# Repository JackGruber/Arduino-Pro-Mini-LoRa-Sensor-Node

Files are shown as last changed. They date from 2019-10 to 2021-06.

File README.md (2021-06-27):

# Arduino Pro Mini TTN LoRaWAN sensor node

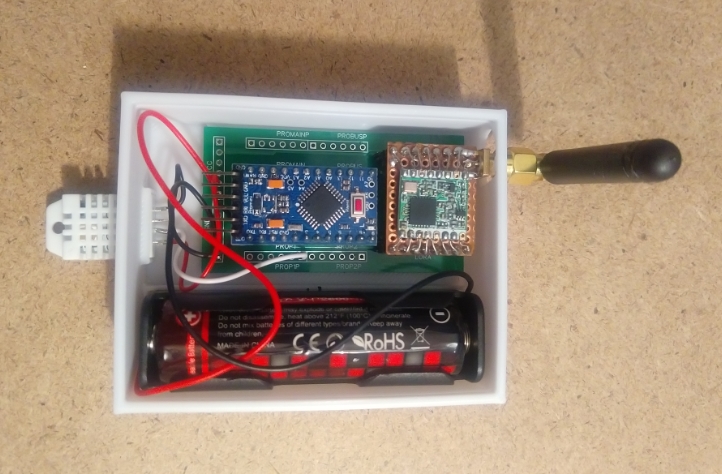
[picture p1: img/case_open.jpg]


`Arduino Pro Mini` TTN LoRaWAN Node with `DHT22` and `RFM95` module powered by an 18650 protected battery.  
The Arduino was converted to [LowPower](https://jackgruber.github.io/2019-12-27-Low-power-Arduino-Pro-Mini/) by desoldering the power LED and the voltage converter.

## Circuit

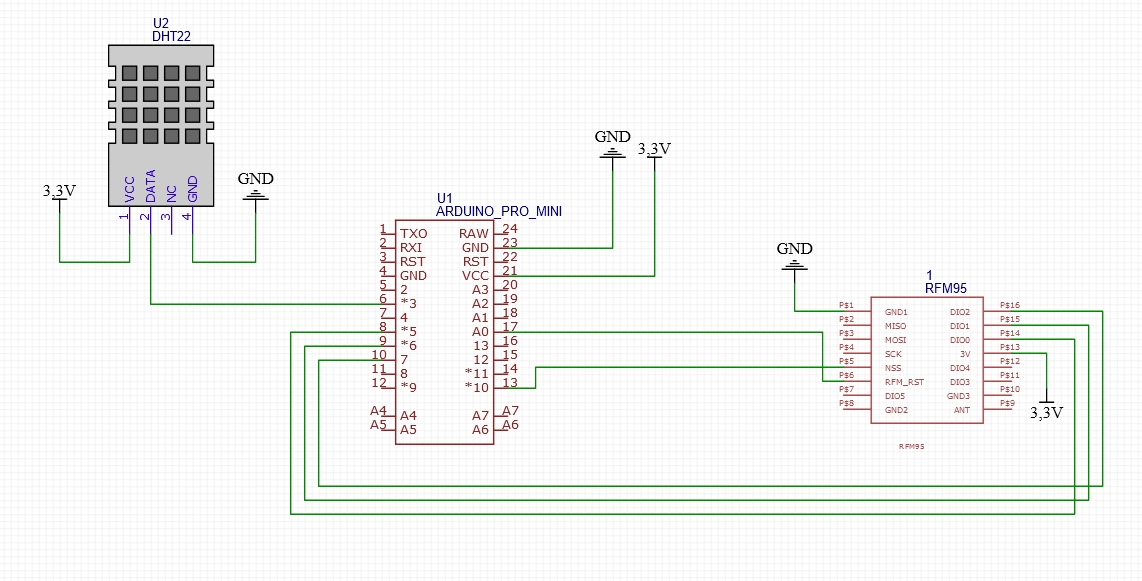
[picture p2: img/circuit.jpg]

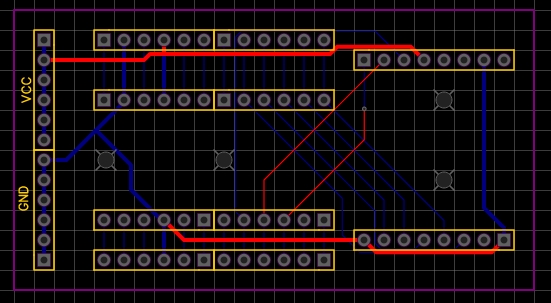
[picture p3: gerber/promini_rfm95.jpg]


## Case

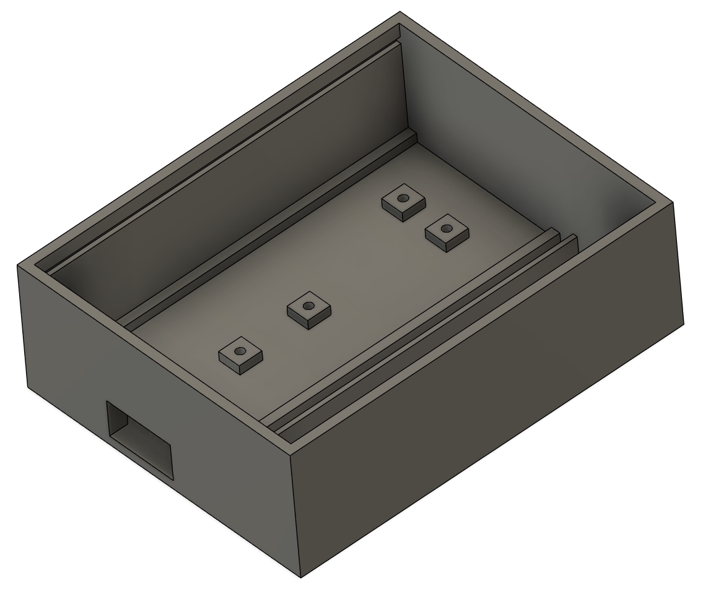
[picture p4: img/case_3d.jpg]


## Diagrams 
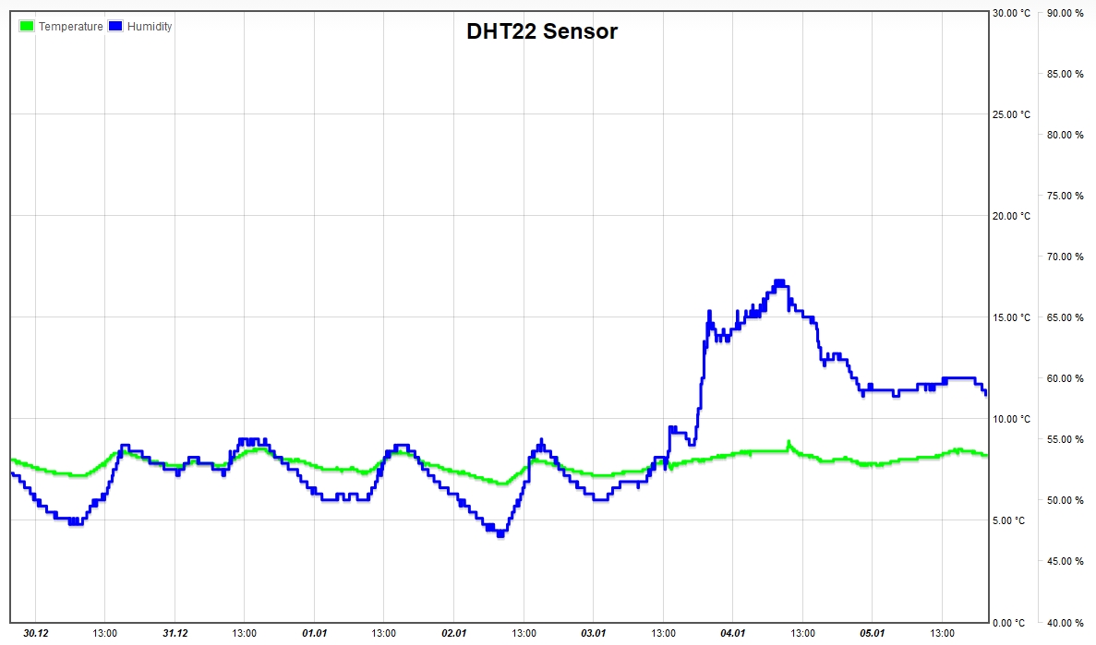
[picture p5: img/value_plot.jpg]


### Battery voltage curve over 12 months with measure and send data all 5 minutes

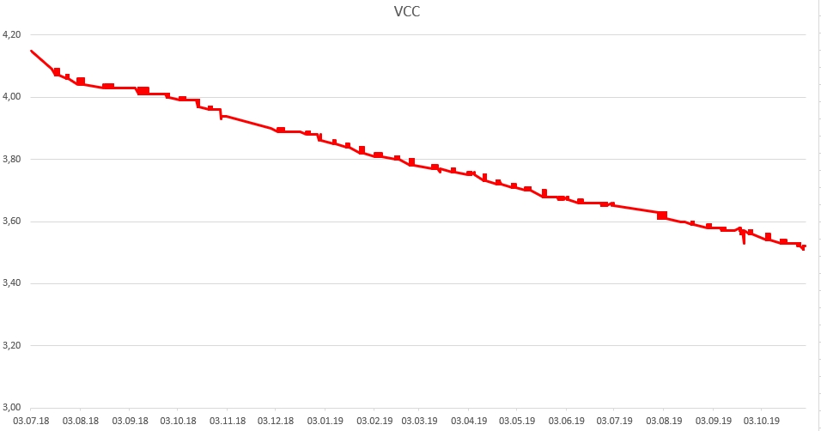
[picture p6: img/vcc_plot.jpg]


## TTN payload decoder (v2)

```javascript
function Decoder(bytes, port) {
  var decoded = {};
  
  decoded.vcc = (bytes[0] + 200)/100;
  
  if(bytes[1] != 255){
    decoded.humidity = bytes[1]; 
    decoded.humidity &= ~(1 << 7);
    if(bytes[1] >> 7 == 1) { decoded.humidity +=0.5 }
  }
  
  if(bytes[2] != 255 || bytes[3] != 255) decoded.temperature = ((bytes[2]<<24>>16 | bytes[3]) / 10);
  return decoded;
}
```

## TTN payload decoder (v3)

```javascript
function decodeUplink(input) {
  var decoded = {};
  decoded.vcc = (input.bytes[0] + 200)/100;
  if(input.bytes[1] != 255){
    decoded.humidity = input.bytes[1]; 
    decoded.humidity &= ~(1 << 7);
    if(input.bytes[1] >> 7 == 1) { decoded.humidity +=0.5 }
  }
  if(input.bytes[2] != 255 || input.bytes[3] != 255) decoded.temperature = ((input.bytes[2]<<24>>16 | input.bytes[3]) / 10);
  
  return {
    data: decoded,
    warnings: [],
    errors: []
  };
}
```

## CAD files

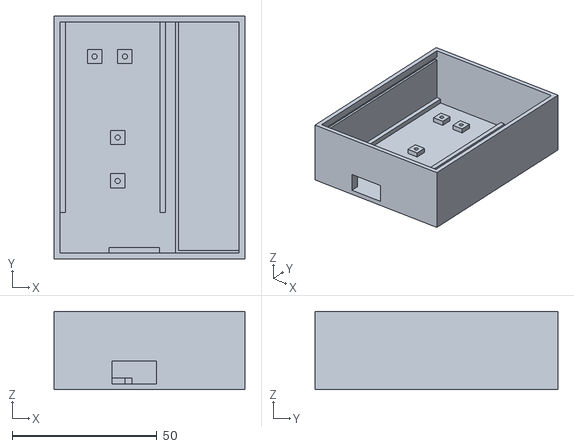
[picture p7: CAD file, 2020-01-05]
3D/LoRa Base Case.stl
66.0 x 84.0 x 27.0

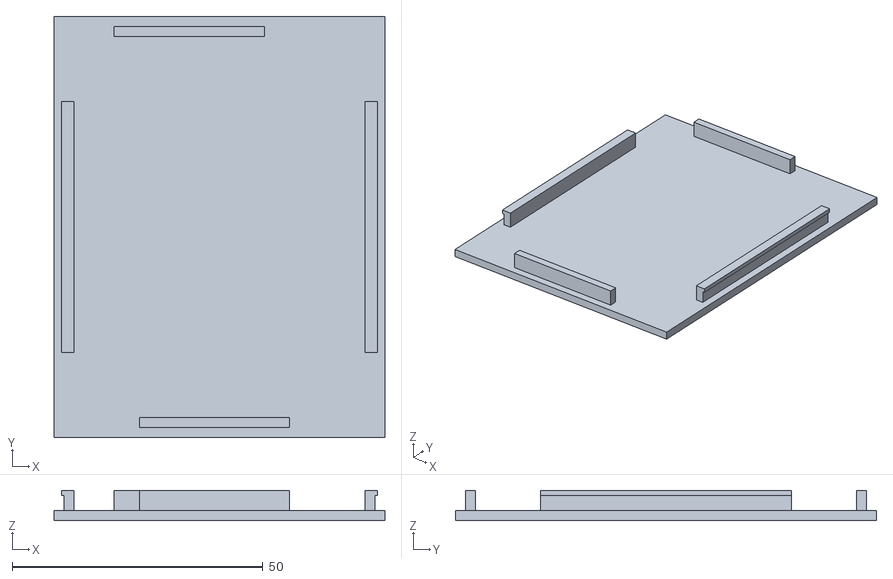
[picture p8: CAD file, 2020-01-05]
3D/Lora Base Case Deckel.stl
66.0 x 84.0 x 6.00

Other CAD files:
3D/LoRa Base Case.f3d
3D/Lora Base Case Deckel.f3d

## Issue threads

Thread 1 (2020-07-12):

Matching Network

meakash, 2020-07-12:
Hi, Sorry to bother you, i was making a similar board and i was stuck at designing a matching network between the ant pin of RFM 95 and the SMA connector, wont that be a problem?

JackGruber, 2020-07-12:
Hi, I'm not sure what do you mean.

The PCB trace between the ANT Pin and the SMA connector should be as short as possible.

meakash, 2020-07-12:
Thank you for the prompt response.
What I am asking is that is there any need to a matching network between the ANT pin and SMA connector?
I read it is always better to have a matching network as there may be losses if there is no matching netowrk.
Did you observe any bad results?

JackGruber, 2020-07-13:
sorry, but I don't know what you mean by:
>any need to a matching network between the ANT pin and SMA connector?

mkbehbeh, 2020-09-01:
I think that what meakash is referring to is the set of inductors/capacitors between the radio transmitter and antenna to match impedance and reduce reflections.
If you look closely at the SX1272/76 board there is already a matching network there to match the LoRa chip to a 50ohm antenna.  As long as you keep your traces short (<< than 1/4 wavelenth) then you should only see the impedance of your monopole (short stub of wire) or dipole (rubber ducky style) which will be matched close enough to 50ohms to not cause a problem.  If you want to use a different antenna that is not matched to 50 ohms then you need to provide your own matching network.  You will also need a matching network if you need to have an extension to the antenna with a length not matched to a multiple of half wavelength.

Closed 2020-07-30.

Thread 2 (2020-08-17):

Using os_queryTimeCriticalJobs before sleeping and sleep wakeup

Praneethsvch, 2020-08-17:
Hi JackGruber,

I am student and using your code I am additionally trying to implement os_queryTimeCriticalJobs before sleeping from one of your articles:  [ESP 32 DeepSleep and LoraWAN OTAA join](https://jackgruber.github.io/2020-04-13-ESP32-DeepSleep-and-LoraWAN-OTAA-join/)

I believe an ideal scenario would look like:
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
with main loop being,

```
void loop(void)
{
    os_runloop_once();
    int seconds = 300;
    if(!os_queryTimeCriticalJobs(ms2osticksRound( (seconds*1000) - 1000 )))
    {
        Serial.println("Can sleep");
        if(GOTO_DEEPSLEEP == true)
        {
           // sleep now
           MCU_sleep();
           // set GOTO_DEEPSLEEP false
           GOTO_DEEPSLEEP = false;
        }
    }
}
```

I would like to request for your valuable suggestion on the following:

1. Firstly I understand that the MCU is put to deep sleep between the transmits, i.e. a TX is scheduled for LORA_TX_INTERVAL and then goes to deep sleep. I see in the following PowerDownTXIntervall function, you have added sleep cycles + 1 which means MCU is going to sleep for a period little longer than LORA_TX_INTERVAL
```
void PowerDownTXIntervall()
{
    Serial.println(F("PowerDown..."));
    Serial.flush();

    int sleep_cycles = LORA_TX_INTERVAL / 8;

    for (int i=0; i<=sleep_cycles+1; i++)
    {
      PowerDownUpdateMicros();
    }

    Serial.println(F("PowerUp..."));
}
```
But the next TX is scheduled after LORA_TX_INTERVAL and does this mean the MCU wakes up from sleep before the for loop is executed? and if yes, does it use interrupts?

2. Secondly, if it does wake up from sleep using interrupt, the `GOTO_DEEPSLEEP` would not be set back to false. Would there be a possible danger that the mcu sleeps indefinitely or blocking the next TX?

Thank you for your valuable time!

JackGruber, 2020-08-18:
Hi @Praneethsvch,

You mix the ESP and ATmega 328 topics ...

>Firstly I understand that the ...

Yes this is correct, but only 8 Seconds more.
I had built this in as a compensation, so that I am below the Duty cycle limit at a 1 channel node.

The ATmega 328 execute after a wake up the code at the same position and can store the variables during a DeepSleep. An ESP32 can't do this!

The addition of os_queryTimeCriticalJobs would look like this for this repro code which is for an ATmega 328:
```c++
void LoraWANDo(void)
{
    if(GO_DEEP_SLEEP == true AND !os_queryTimeCriticalJobs(ms2osticksRound( (seconds*1000) - 1000 )))
    {
      PowerDownTXIntervall();
      GO_DEEP_SLEEP = false;
    }
    else
    {
      os_runloop_once();
    }
}
```

> Secondly, if it does wake up from sleep using interrupt, the GOTO_DEEPSLEEP would not be set ...

The `GOTO_DEEPSLEEP` would be set to false in `void LoraWANDo(void)` on the ESP all vars are reinizialized after a deep sleep!
Because the ESP32 reboots completely!

In the next few days I will release a project for an ESP32, which has been running for months.
Probably i will release also an update for the Arduino-Pro-Mini-LoRa-Sensor-Node.

Regards
Alex

Praneethsvch, 2020-08-19:
Thanks for your valuable reply and time!

Closed 2020-08-19.

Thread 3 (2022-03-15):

No JoinAccept

CK1-CK, 2022-03-15:
Hi Jack,

thank you very much for providing this code. It is really super easy to do an implementation.

But unfortunately I have some problems with the connection to TheThingsNetwork (TTN)

The handshake is obviously initalized, this is shown to me in the console. Unfortunately there is no JoinAccept. Unfortunately I do not know why this is :(

There is no payload being transferred.

i also tried other implementations (https://github.com/lnlp/LMIC-node) with the same result (no JoinAccept)

At the moment I really don't know what I'm doing wrong.

Maybe it is the different PIN Mapping:
```
// PIN definition for module
#define PIN_LMIC_NSS  10
#define PIN_LMIC_RST  9
#define PIN_LMIC_DIO0 2
#define PIN_LMIC_DIO1 8
#define PIN_LMIC_DIO2 A0 //Not connected from SX1276 to Arduino
```

| Arduino PIN| SX1276 PIN|
| VCC          | VCC         |
| GND          | GND         |
| 2 (INT0)     | DIO0        |
| 8            | DIO1        |
| 9            | Rest        |
| 10 (SS)      | NSS         |
| 11 (MOSI)    | MOSI        |
| 12 (MISO)    | MISO        |
| 13 (SCK)     | SCK         |

**Serial Output:**
```
Starting DHT ...
Sketch: 1.0.0.-
Builddate:
MCUSR: EXTRF
LMIC: 4.1.1.0
LoRaWAN_Setup ...
DHT: TIMEOUT
nan %
nan °C
Packet queued
194510: EV_JOINING
435214: EV_TXSTART
829042: EV_JOIN_TXCOMPLETE: no JoinAccept
4534017: EV_TXSTART
4927852: EV_JOIN_TXCOMPLETE: no JoinAccept
```

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

I am grateful for any tips!

best regards
CK1

CK1-CK, 2022-03-15:
Why you don't use the SPI Interface?
https://github.com/JackGruber/Arduino-Pro-Mini-LoRa-Sensor-Node/blob/master/img/circuit.jpg

CK1-CK, 2022-03-21:
It was a hardware problem. My SX1276 was defective.

Closed 2022-03-21.

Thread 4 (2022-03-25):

Feature Request: Interrupt DoorSwitch (Alarm System) --> Fire a LoRa Package immediatly

CK1-CK, 2022-03-25:
Servus,

Ich möchte deinen Code benutzen um eine Tür Alarmanlage zu bauen. Der Türschalter soll an Pin 3 (Interrupt Pin) ausgelesen werden. Ich bin mir allerdings unsicher, wie ich das planen der Lora Pakete machen soll bzw. den PowerDown umgehe. Stromverbrauch ist bei mir nicht wichtig, da ich an einem 5V Netzeil hänge.

- Ich möchte alle 5 min einen Watchdog senden.
- Sobald der Türschalter auslöst, soll sofort ein TTN Lora Paket verschickt werden.

Wie kann man das am Besten umsetzen.

Vielen Dank schon im Voraus.
CK1

----------------------------------------

Hi,

I would like to use your code to build a door alarm system. The door switch is to be read out at pin 3 (interrupt pin). However, I am unsure how to plan the Lora packages and how to avoid the PowerDown. Power consumption is not important for me, as I am connected to a 5V power supply.

- I would like to send a watchdog every 5 minutes.
- As soon as the door switch is triggered, a TTN Lora packet should be sent immediately.

What is the best way to implement this?

Many thanks in advance.
CK1

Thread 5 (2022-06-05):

How is the sleep time defined and where is the wake up call

willmendil, 2022-06-05:
Hi,

I'm quite new at using interrupts with arduino hence i am having difficulties understanding your code.
Could you enlighten me on when in the powerdown functions the sleeping time is defined? I understand it's related to `LORA_TX_INTERVAL` and that the number of sleep cycles is compared. But I don't understand why there a division by 8 and where the arduino is waken up

thanks

JackGruber, 2022-06-06:
The `WDTCSR` register is set to 8 seconds, therefore the micro controller wake up every 8 seconds to check if the sleep time from `LORA_TX_INTERVAL` has reached.

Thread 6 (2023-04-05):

Is there a mistake in your schematic? MISO and MOSI are NC

DeflateAwning, 2023-04-05:
I would expect that MISO and MOSI need to be connected for this system to work.

stkdiretto, 2025-03-30:
That is correct. The schematics of the board appear to be correct, as opposed to the circuit diagram.

Connections are:

| Arduino | RFM95 |
| --- | --- |
| GND | GND |
| 5 | DIO0 |
| 6 | DIO1 |
| 7 | DIO2 |
| 10 | NSS |
| 11 | MOSI |
| 12 | MISO |
| 13 | SCK |
| A0 | RST |
| VCC | 3V3 |
| GND | GND |

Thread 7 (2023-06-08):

Empty values after deep sleep

guillebot, 2023-06-08:
Hi! I'm trying to use your project, since I'm finding it very nice and tidy. Congrats, and thank you.

It works mostly, but sometimes after deep sleep it just sends a empty payload and goes to sleep again.

Even with correct DHT measurements (I had to add a little delay there in order to give it time to turn on). Could be that?

I added 3 seconds split in 3 delay() calls.

Any hint would be very welcomed.

Thanks

guillebot, 2023-06-08:
More info:

It seems like it just wake up and send the message, then goes to taking the measures and sleep again

PowerUp...
21326936: EV_TXSTART   <----- sends empty packet
Delay ...done!   <--- my delay
DHT: OK
DHT Model: 2
27.80 %
27.40 °C
A0: 166
Packet queued
21706732: EV_TXCOMPLETE . .
PowerDown...

guillebot, 2023-06-08:
This gets a lot worse with 8 seconds sleep, when I change the internal timer to 0.5 or 1.0 seconds it works almost allways.

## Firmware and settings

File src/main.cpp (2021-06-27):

#include <Arduino.h>
#include "io_pins.h"
#include "functions.h"
#include "lorawan.h"
#include "global.h"
#include "powerdown.h"
#include "version.h"
#include "version_build.h"

void setup()
{
  Serial.begin(115200);
  Serial.println(F("Starting DHT ..."));
  Serial.println("Sketch: " VERSION_MAJOR "." VERSION_MINOR "." VERSION_PATCH "." BUILD_COMMIT "-" BUILD_BRANCH);
  Serial.println("Builddate: " BUILD_DATE " " BUILD_TIME);
  PrintResetReason();
  LoRaWANVersion();
  delay(3000);
  DHTSENSOR.setup(PIN_DHT);
  PowerDownSetupWatchdog();
  Setup_Pins();
  Blink_Info_LED();
  LoRaWANSetup();
}

void loop()
{
  LoRaWANDo();
}

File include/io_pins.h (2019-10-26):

#define PIN_DHT 3
#define PIN_INFO_LED 9

// PIN definition for module
#define PIN_LMIC_NSS  10
#define PIN_LMIC_RST  A0
#define PIN_LMIC_DIO0 5
#define PIN_LMIC_DIO1 6
#define PIN_LMIC_DIO2 7

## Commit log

2019-10-28 Add Adafruit Unified Sensor for DHT
2019-10-28 Add DHT Sensor setup
2019-10-28 Add missing deep sleep var update
    [lorawan.cpp]
2019-10-28 Add PowerDown (DeepSleep) functions
2019-10-28 Rename DHT Sensor
2019-10-30 BUG: Correct LORA_DATA size
    [lorawan.cpp]
2019-10-30 Chnage DHT Sensordata to new function ReadDHTSensor
2019-10-30 Move WatchDogSetup to Top, remove old DHT22 sensor function, add new function DHT22
2019-10-30 remove old arduino project folder
2019-10-30 BUG: wrong value check for NAN
    [lorawan.cpp]
2019-10-30 Add deleay for DHT22 after power up and remove startup read
2019-10-31 Remove Serial.Print because timing problems in LMIC
    [functions.cpp]
2019-11-02 Print reset reason
2019-11-03 Init DHT sensor
2019-11-03 Increase LED flash time
2019-11-03 BUG: Precision (everytime + 1)
    [lorawan.cpp]
2019-12-28 Add conf for new sensor
2020-01-05 Add 3d printer files
    [LoRa Base Case.f3d, LoRa Base Case.stl, Lora Base Case Deckel.f3d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]
2020-01-05 Add pcm gerber file
2020-01-05 change to lower case
